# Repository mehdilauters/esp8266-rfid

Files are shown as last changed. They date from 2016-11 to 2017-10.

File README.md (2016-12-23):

# ID-12LA to tcp bridge
http://cdn.sparkfun.com/datasheets/Sensors/ID/ID-2LA,%20ID-12LA,%20ID-20LA2013-4-10.pdf

Configure your parameters in user/user_config.h

run on your server 

````
python /tmp/server.py 5555
starting up on 0.0.0.0 port 5555
waiting for a connection
client connected:waiting for a connection
 ('54.145.90.17', 44844)
tag 7800F011A6 received
tag 7800F8CC97 received
````

To enable the webui, please run ````bower install first````

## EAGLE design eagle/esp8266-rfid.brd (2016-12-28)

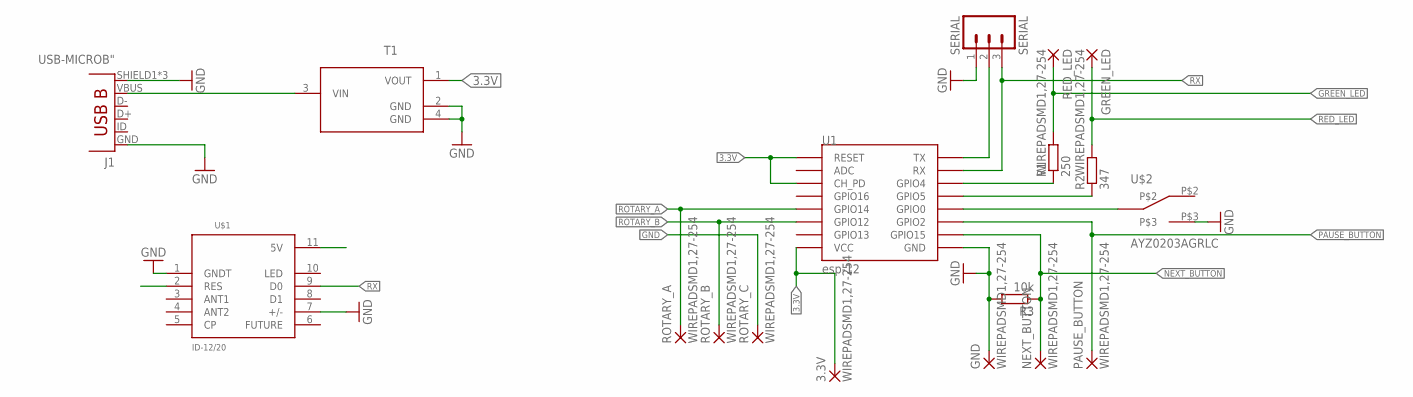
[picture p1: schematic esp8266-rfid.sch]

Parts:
3.3V: WIREPADSMD1,27-254; SMD1,27-2,54
GND: WIREPADSMD1,27-254; SMD1,27-2,54
GREEN_LED: WIREPADSMD1,27-254; SMD1,27-2,54
J1: USB-MICROB"; USB-B-MICRO-SMD_V03
NEXT_BUTTON: WIREPADSMD1,27-254; SMD1,27-2,54
PAUSE_BUTTON: WIREPADSMD1,27-254; SMD1,27-2,54
R1: 250; R0603
R2: 347; R0603
R3: 10k; R0603
RED_LED: WIREPADSMD1,27-254; SMD1,27-2,54
ROTARY_A: WIREPADSMD1,27-254; SMD1,27-2,54
ROTARY_B: WIREPADSMD1,27-254; SMD1,27-2,54
ROTARY_C: WIREPADSMD1,27-254; SMD1,27-2,54
SERIAL: SERIAL; 1X03
T1: L78L33ACUTR; SOT150P400X160-4N
U1: esp-12; ESP12-SMD
U$1: ID-12/20; ID-12
U$2: AYZ0203AGRLC

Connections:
3.3V: 3.3V.1, T1.1 (VOUT), U1.CH_PD, U1.RESET, U1.VCC
GND: GND.1, J1.GND, J1.SHIELD1 (SHIELD), J1.SHIELD2 (SHIELD), J1.SHIELD3 (SHIELD), R3.2, ROTARY_C.1, SERIAL.1, T1.2 (GND), T1.4 (GND), U1.GND, U$1.1 (GNDT), U$1.7 (+/-), U$2.P$3
GREEN_LED: R1.2, RED_LED.1
unnamed: U1.GPIO0, U$2.P$1 (COM)
unnamed: R1.1, U1.GPIO4
NEXT_BUTTON: NEXT_BUTTON.1, R3.1, U1.GPIO15
PAUSE_BUTTON: PAUSE_BUTTON.1, U1.GPIO2
RED_LED: GREEN_LED.1, R2.2
RESET: R2.1, U1.GPIO5
ROTARY_A: ROTARY_A.1, U1.GPIO14
ROTARY_B: ROTARY_B.1, U1.GPIO12
RX: SERIAL.3, U1.RXD0 (RX), U$1.9 (D0)
TX: SERIAL.2, U1.TXD0 (TX)
VBUS: J1.VBUS, T1.3 (VIN), U$1.2 (RES), U$1.11 (5V)

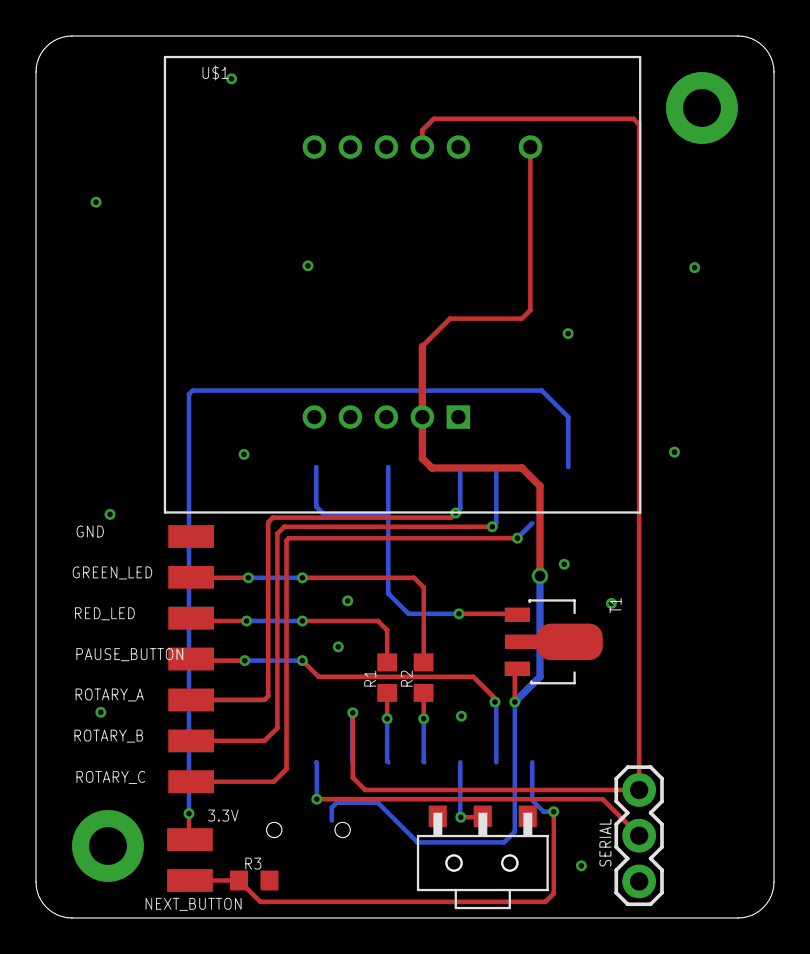
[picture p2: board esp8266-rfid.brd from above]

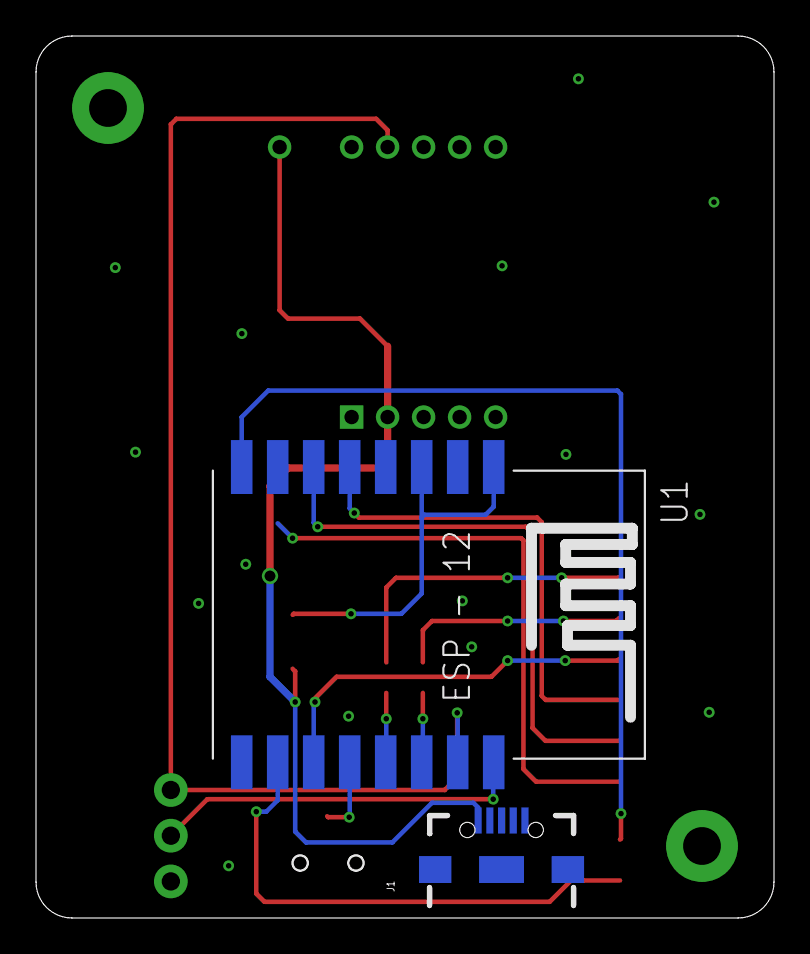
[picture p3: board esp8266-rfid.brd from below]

Board: 2 copper layers, 41.0 x 49.0 mm, 18 parts (2 on the bottom side), 14 nets.

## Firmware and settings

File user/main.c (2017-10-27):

#include "rboot-api.h"


#include "version.h"
#include "config.h"
#include "espressif/esp_common.h"
#include "esp/gpio.h"
#include "esp/uart.h"
#include "FreeRTOS.h"
#include "task.h"
#include "flash.h"
#include <string.h>

#include <dhcpserver.h>
#include <lwip/api.h>

#include "esplibs/libnet80211.h"

#include "captdns.h"
#include "webserver.h"
#include "rfid.h"
#include "ota.h"
#include "rotary.h"

#include <unistd.h>

#define T uint8_t
#include "fifo.h"

#define SERIAL_BUFFER_SIZE 64

static bool _is_connected;
fifo_t serial;
uint8_t serial_buffer[SERIAL_BUFFER_SIZE];
struct sdk_station_config wifi_config;

unsigned int frc2_freq = 0;

void set_red_led_blink(bool _status, unsigned int _frequency) {
  
  if( _frequency == 0 ) {
    timer_set_interrupts(FRC1, false);
    timer_set_run(FRC1, false); 
    gpio_write(RED_LED_PIN, _status);
  } else {
    timer_set_frequency(FRC1, _frequency);
    timer_set_interrupts(FRC1, true);
    timer_set_run(FRC1, true);
  }
}


void set_red_led(bool _status) {
  set_red_led_blink(_status, 0);
}

void set_green_led_blink(bool _status, unsigned int _frequency) {
  frc2_freq = _frequency;
  if( _frequency == 0 ) {
    timer_set_interrupts(FRC2, false);
    timer_set_run(FRC2, false); 
    gpio_write(GREEN_LED_PIN, _status);
  } else {
    timer_set_frequency(FRC2, _frequency);
    timer_set_interrupts(FRC2, true);
    timer_set_run(FRC2, true);
  }
}

void set_green_led(bool _status) {
  set_green_led_blink(_status, 0);
}

bool save_network(char * _essid, char *_password) {
  printf("saving essid=%s, password=%s to flash\n",_essid, _password);
  int res_ssid = flash_key_value_set("ssid",_essid);
  int res_wpa = flash_key_value_set("pwd",_password);
  if(res_ssid == 0 || res_wpa == 0) {
    printf("Error saving to flash\n");
    flash_erase_all();
    return save_network(_essid, _password);
  }
  
  return true;
}

bool load_network(struct sdk_station_config* _config) {
  printf("LOADING\n");
  char buffer[128];
  int res = flash_key_value_get("ssid",buffer);
  if(res == 0) {
    printf("n: no ssid\n");
    return false;
  }
  
  strcpy((char*)_config->ssid, buffer);
  
  res = flash_key_value_get("pwd",buffer);
  if(res == 0) {
    printf("n: no pwd\n");
    return false;
  }
  
  strcpy((char*)_config->password, buffer);
  printf("found %s\n", _config->ssid);
  return true;  
}


bool save_server(char * _server, int _port) {
  printf("saving server http://%s:%d to flash\n",_server, _port);
  int res_server = flash_key_value_set("server",_server);
  
  char port[5];
  if(sprintf(port, "%d", _port)) {
    int res_port = flash_key_value_set("port",port);
    
    if(res_server == 0 || res_port == 0) {
      printf("Error saving to flash\n");
      flash_erase_all();
      return false;
    }
  } else {
    printf("bad port %d\n", _port);
  }
  
  return false;
}

bool load_server(char * _server, int *_port) {
  int res_server = flash_key_value_get("server",_server);
  
  char buffer[5];
  int res_port = flash_key_value_get("port",buffer);
  
  if(res_server == 1 && res_port == 1) {
    if( _port != NULL ) {
      *_port = strtol(buffer, NULL, 10);
    }
    return true;
  } else {
    return false;
  }
}


bool get_button_pressed() {
  return gpio_read(0) != false;
}

void connect(struct sdk_station_config* _config) {
  printf("connecting to %s\n",_config->ssid);
  sdk_wifi_set_opmode(STATION_MODE);
  sdk_wifi_station_set_config(_config);
}

void setup_ap() {
  printf("creating %s\n", DEFAULT_SSID);
  
  sdk_wifi_set_opmode(SOFTAP_MODE);
  struct ip_info ap_ip;
  IP4_ADDR(&ap_ip.ip, 172, 16, 0, 1);
  IP4_ADDR(&ap_ip.gw, 0, 0, 0, 0);
  IP4_ADDR(&ap_ip.netmask, 255, 255, 0, 0);
  sdk_wifi_set_ip_info(1, &ap_ip);
  
  struct sdk_softap_config ap_config = {
    .ssid = DEFAULT_SSID,
    .ssid_hidden = 0,
    .channel = 3,
    .ssid_len = strlen(DEFAULT_SSID),
    .authmode = AUTH_OPEN,
    .password = "",
    .max_connection = 3,
    .beacon_interval = 100,
  };
  sdk_wifi_softap_set_config(&ap_config);
  
  ip_addr_t first_client_ip;
  IP4_ADDR(&first_client_ip, 172, 16, 0, 2);
  dhcpserver_start(&first_client_ip, 4);
  captdnsInit();
}

bool is_connected() {
  return _is_connected;
}


bool get_serial(uint8_t *_c) {
  if(! fifo_isempty(&serial)) {
    *_c = fifo_pop(&serial);
    return true;
  }
  return false;
}

void serial_task(void *pvParameters) {
  char c;
  while(1) {
    if (read(0, (void*)&c, 1)) { // 0 is stdin
      if(! fifo_isfull(&serial)) {
        fifo_push(&serial, c);
        printf("%c\n",c);
      }
    }
  }
}

static void wifi_task(void *pvParameters) {
  uint8_t status = 0;
  uint8_t retries = 30;
    while (1) {
      _is_connected = false;
      
      while ((status != STATION_GOT_IP) && (retries)) {
        status = sdk_wifi_station_get_connect_status();
        printf("%s: status = %d\n\r", __func__, status);
        --retries;
        if (status == STATION_WRONG_PASSWORD) {
          printf("WiFi: wrong password\n\r");
          break;
        } else if (status == STATION_NO_AP_FOUND) {
          printf("WiFi: AP not found\n\r");
          break;
        } else if (status == STATION_CONNECT_FAIL) {
          printf("WiFi: connection failed\r\n");
          break;
        }
        vTaskDelay(1000 / portTICK_PERIOD_MS);
      }
      
      if(retries == 0) {
        setup_ap();
        int sec = 0;
        bool sleep = false;
        while(true) {
          if( sec > MAX_AP_DURATION && ! sleep) {
            sleep = true;
            printf("Sleeping\n");
//             system_deep_sleep_set_option()
//             sdk_system_deep_sleep(UINT32_MAX);
            sdk_wifi_station_stop();
            sdk_wifi_softap_stop();
          }
          vTaskDelay(1000 / portTICK_PERIOD_MS); 
          sec ++;
        }
      }
      
      while ((status = sdk_wifi_station_get_connect_status())
        == STATION_GOT_IP) {
        if ( ! _is_connected ) {
          set_red_led(false);
          printf("WiFi: Connected\n\r");
          _is_connected = true;
        }
        vTaskDelay(500 / portTICK_PERIOD_MS);
        }
        
        _is_connected = false;
      printf("WiFi: disconnected\n\r");
      vTaskDelay(1000 / portTICK_PERIOD_MS);
    }
}

static void buttons_task(void *pvParameters) {
  uint32_t next_ts = 0;
  uint32_t playpause_ts = 0;
  
  bool playpause_fired = false;
  bool next_fired = false;
  
  while(true) {
    bool next = gpio_read(NEXT_PUSH_PIN);
    // gpio0 has a pulldown
    bool alternate = !gpio_read(ALTERNATE_PUSH_PIN);
    
    
    if(next) {
      if(next_ts == 0) {
        next_ts = xTaskGetTickCount()*portTICK_PERIOD_MS;
      }
      if( ! next_fired ) {
        if(xTaskGetTickCount()*portTICK_PERIOD_MS - next_ts > BUTTON_PRESSED_DELAY) {
          if(alternate) {
            push_tag(NEXT_ALTERNATE_TAG);
          } else {
            push_tag(NEXT_TAG);
          }
          next_fired = true;
        }
      }
    } else {
      next_fired = false;
      next_ts = 0;
    }
    
    long value = get_encoder_value();
    if( value != 0 ) {
      if(value > 0) {
        if(alternate) {
          push_tag(UP_ALTERNATE_TAG);
        } else {
          push_tag(UP_TAG);
        }
      } else {
        if(alternate) {
          push_tag(DOWN_ALTERNATE_TAG);
        } else {
          push_tag(DOWN_TAG);
        }
      }
    }      
    
    bool playpause = ! gpio_read(PLAYPAUSE_PUSH_PIN);
    if(playpause) {
      if(playpause_ts == 0) {
        playpause_ts = xTaskGetTickCount()*portTICK_PERIOD_MS;
      }
      if( ! playpause_fired ) {
        if(xTaskGetTickCount()*portTICK_PERIOD_MS - playpause_ts > BUTTON_PRESSED_DELAY) {
          playpause_fired = true;
          if(alternate) {
            push_tag(PAUSE_ALTERNATE_TAG);
          } else {
            push_tag(PAUSE_TAG);
          }
        }
      }
    } else {
      playpause_ts = 0;
      playpause_fired = false;
    }
    
//     printf("program %d next %d  play_pause %d\n",program, next, playpause);
    vTaskDelay(100 / portTICK_PERIOD_MS);
  }
}


void frc1_interrupt_handler(void)
{
  gpio_toggle(RED_LED_PIN);
}

void frc2_interrupt_handler(void)
{
  /* FRC2 needs the match register updated on each timer interrupt */
  timer_set_frequency(FRC2, frc2_freq);
  gpio_toggle(GREEN_LED_PIN);
}

//Init function 
void user_init() {
  _is_connected = false;
  fifo_init(&serial, serial_buffer, SERIAL_BUFFER_SIZE);
  
  uart_set_baud(0, 9600);
  xTaskCreate(serial_task, (const char *)"serial_task", 512, NULL, 2, NULL);
  
  xTaskCreate(buttons_task, (const char *)"buttons_task", 512, NULL, 2, NULL);
  
  timer_set_interrupts(FRC1, false);
  timer_set_run(FRC1, false);
  _xt_isr_attach(INUM_TIMER_FRC1, frc1_interrupt_handler, NULL);
  
  timer_set_interrupts(FRC2, false);
  timer_set_run(FRC2, false);
  _xt_isr_attach(INUM_TIMER_FRC2, frc2_interrupt_handler, NULL);
  
  uint32_t id = sdk_system_get_chip_id();
  printf("#%d\n", id);
  printf("%s %s %s\n",BUILD_DATE, BUILD_TIME, GIT_VERSION);
  rfid_start();
  webserverInit();
  
  gpio_enable(NEXT_PUSH_PIN, GPIO_INPUT);
  gpio_enable(ALTERNATE_PUSH_PIN, GPIO_INPUT);
  
  gpio_enable(GREEN_LED_PIN, GPIO_OUTPUT);
  set_green_led(false);
  
  gpio_enable(RED_LED_PIN, GPIO_OUTPUT);
  set_red_led(false);
  
  rotary_init(ROTARY_A, ROTARY_B, ROTARY_C);
  
  if( load_network(&wifi_config)) {
    set_red_led_blink(true, 5);
    connect(&wifi_config);
    xTaskCreate(wifi_task, (const char *)"wifi_task", 512, NULL, 1, NULL);
  } else {
    set_red_led_blink(true, 1);
    flash_erase_all();
    setup_ap();
  }
}

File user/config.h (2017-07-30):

#ifndef CONFIG_HPP
#define CONFIG_HPP

#define DEFAULT_SSID "esp-rfid"

// should be firmwar_1.bin on the server
#define TFTP_IMAGE_FILENAME "esp-rfid.bin"

#define MAX_AP_DURATION 60

#define ALTERNATE_PUSH_PIN 0
#define PLAYPAUSE_PUSH_PIN 2
#define GREEN_LED_PIN 4
#define RED_LED_PIN 5

#define ROTARY_B 12
#define ROTARY_C 13
#define ROTARY_A 14

#define NEXT_PUSH_PIN 15



#define BUTTON_PRESSED_DELAY 100

#define UP_TAG "AF00AF00AC"
#define DOWN_TAG "AF00AF00AD"
#define NEXT_TAG "AF00AF00AE"
#define PAUSE_TAG "AF00AF00AF"

#define ALTERNATE_TAG "AF00AF00BA"
#define UP_ALTERNATE_TAG "AF00AF00BB"
#define DOWN_ALTERNATE_TAG "AF00AF00BC"
#define NEXT_ALTERNATE_TAG "AF00AF00BD"
#define PAUSE_ALTERNATE_TAG "AF00AF00BD"

#define RAW_TCP
#endif

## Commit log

2016-10-08 New TCP connexion for each tag + virtal tag for button
2016-11-06 Adding EAGLE schematic
    [main.brd, main.sch]
2016-11-11 EAGLE moved to new folder
    [esp8266-rfid.brd, esp8266-rfid.sch]
2016-11-28 WEBUI: adding current config
2016-12-01 SDK switch to rtos
2016-12-01 SDK switch WEBSERVER init
2016-12-08 SDK: uart working
2016-12-27 EAGLE + http push
    [esp8266-rfid.brd, esp8266-rfid.sch]
2016-12-27 EAGLE: rotary fix
    [esp8266-rfid.sch]
2016-12-28 ROTARY_ENCODER + red led
    [esp8266-rfid.brd]
2016-12-28 EAGLE: resistance value update
    [esp8266-rfid.brd, esp8266-rfid.sch]
2016-12-29 LED: green led status
2016-12-29 TAG config + buttons
2016-12-31 BUTTONS + OTA green led
2017-04-20 DEEZER: get request fix
    [config.h]
2017-05-03 AP: switch off ap after MAX_DURATION
2017-07-30 BUTTONS: add alternate button

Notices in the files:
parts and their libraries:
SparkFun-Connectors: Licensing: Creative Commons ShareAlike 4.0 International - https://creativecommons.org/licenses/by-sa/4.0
